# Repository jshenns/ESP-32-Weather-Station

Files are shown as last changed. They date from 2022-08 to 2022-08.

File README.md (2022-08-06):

# ESP-32-Weather-Station
Weather station that can send data to you via wifi. Meausres temperature, pressure, humidity. Also detects Lightning.

I wanted a weather station that could send data to me over wifi. This is it, it uses a BME-280 Sensor for temperature, pressure, and humidity. It uses an AS3935 Franklin lightning detector and 100nH coil for lightning detection. I initially prototyped it using the Sparkfun breakouts for those sensors, and then integrated everything into a PCB. Whole system centeres around the ESP-32 WROOM 32D module. The Blynk platform is used to stream the data over wifi for now.

Here is the board rendered in Eagle:

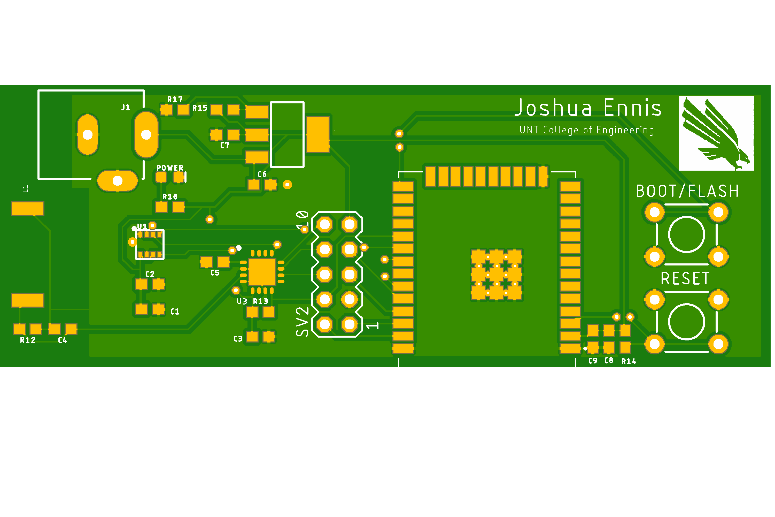
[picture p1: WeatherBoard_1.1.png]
board


Here is the board IRL:

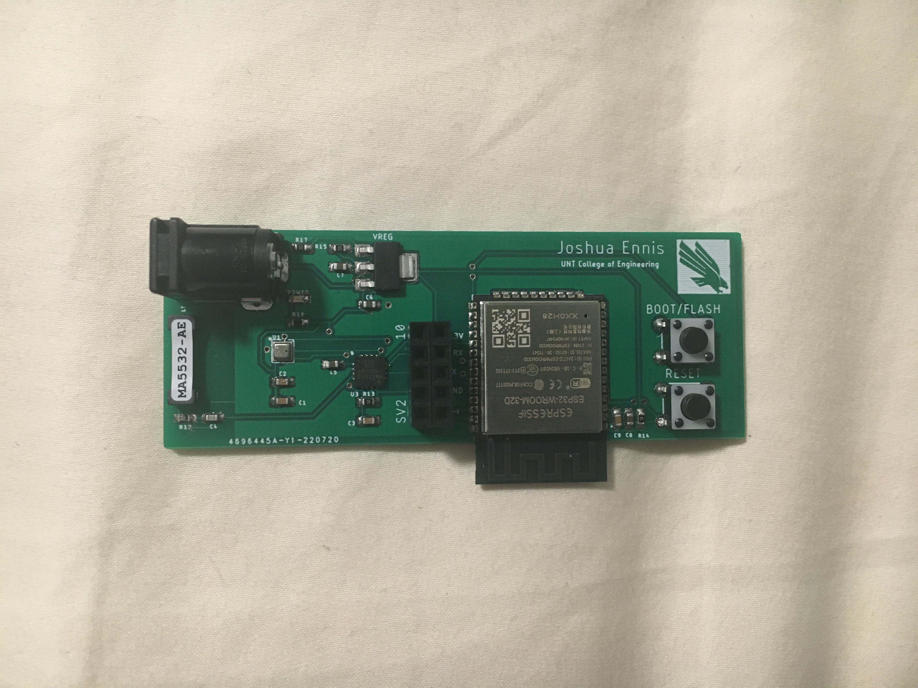
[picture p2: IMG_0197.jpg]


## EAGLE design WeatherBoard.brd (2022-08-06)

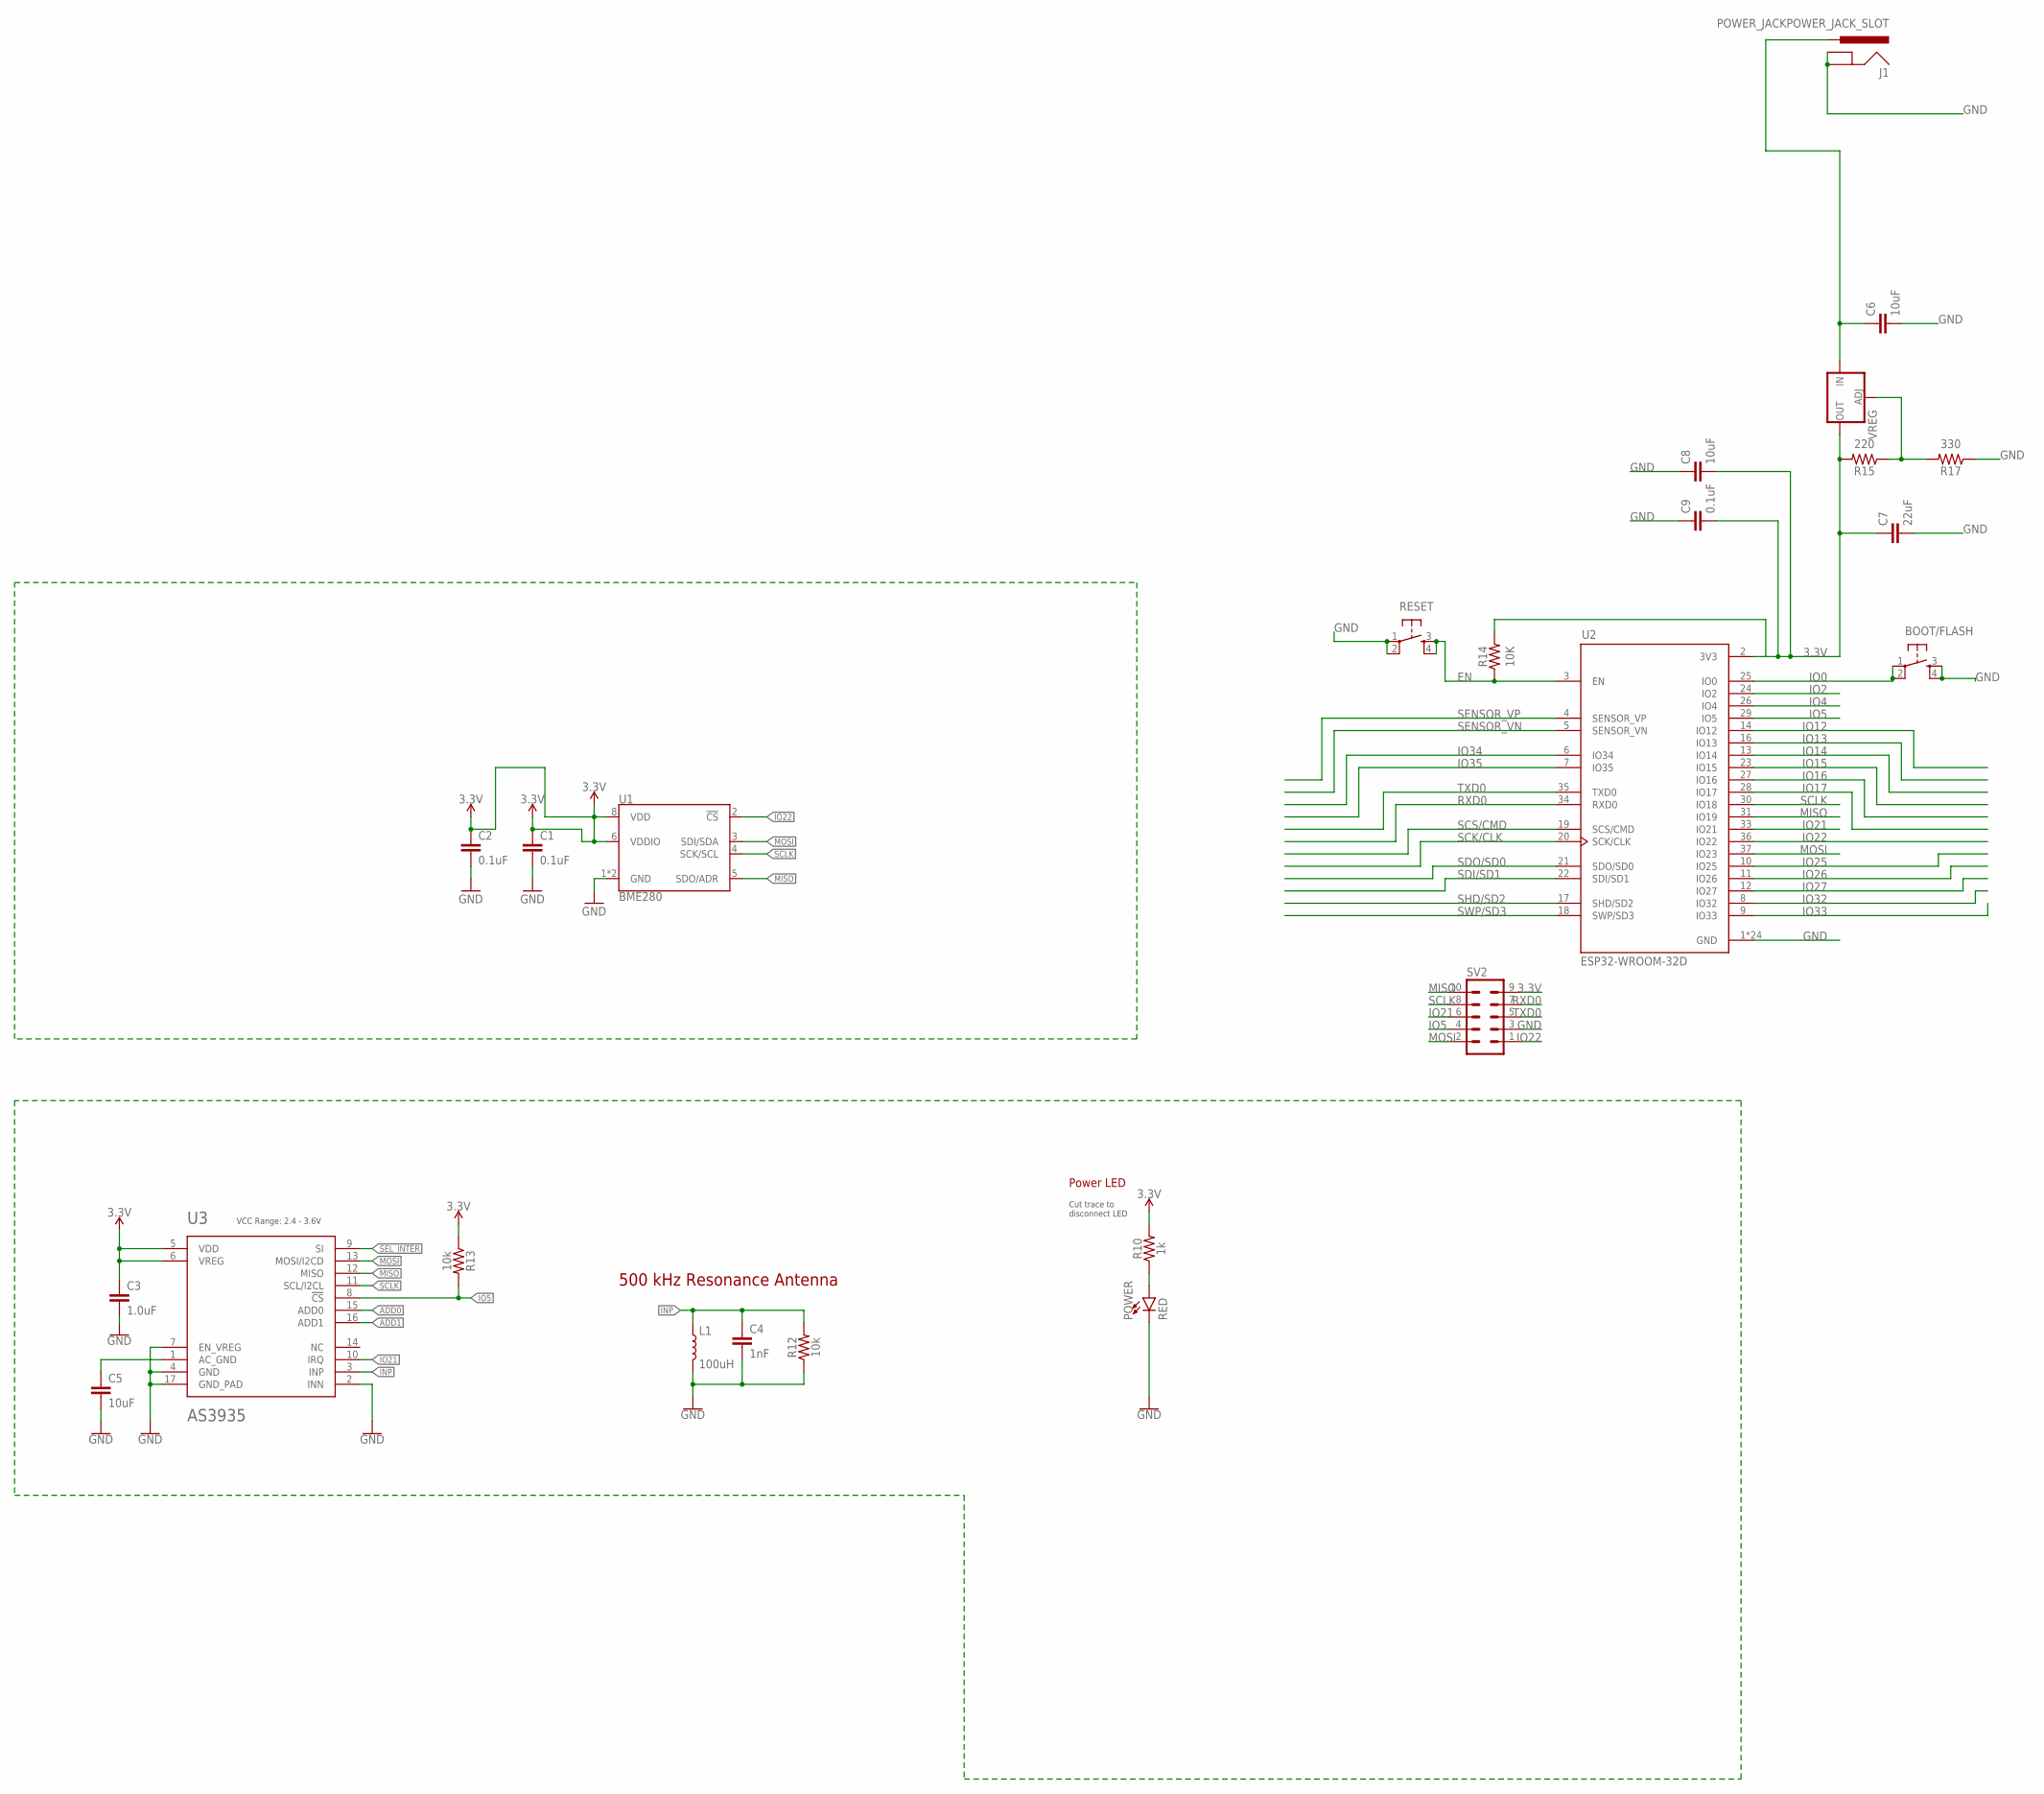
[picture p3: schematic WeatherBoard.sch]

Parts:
BOOT/FLASH: TAC_SWITCHPTH; TACTILE-PTH
C1, C2, C9: 0.1uF; 0603
C3: 1.0uF; 0603
C4: 1nF; 0603
C5, C6, C8: 10uF; 0603
C7: 22uF; 0603
J1: POWER_JACKPOWER_JACK_SLOT; POWER_JACK_PTH_SLOT
L1: 100uH; MA5532-AE
POWER: RED; LED-0603
R10: 1k; 0603
R12, R13: 10k; 0603
R14: 10K; 0603
R15: 220; 0603
R17: 330; 0603
RESET: TAC_SWITCHPTH; TACTILE-PTH
SV2: MA05-2
U1: BME280; LGA-8-2.5X2.5
U2: ESP32-WROOM-32D; MODULE_ESP32-WROOM-32D
U3: AS3935; 16LD_MLPQ
VREG: ADJWEATHERSTATION; VREG_NCP1117STAT3G

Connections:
3.3V: C1.1, C2.1, C3.1, C7.1, C8.2, C9.2, R10.2, R13.1, R14.2, R15.2, SV2.9, U1.6 (VDDIO), U1.8 (VDD), U2.2 (3V3), U3.5 (VDD), U3.6 (VREG), VREG.2 (OUT), VREG.4 (OUT)
ADD0: U3.15 (ADD0)
ADD1: U3.16 (ADD1)
EN: R14.1, RESET.3, RESET.4, U2.3 (EN)
GND: BOOT/FLASH.3, BOOT/FLASH.4, C1.2, C2.2, C3.2, C4.2, C5.2, C6.2, C7.2, C8.1, C9.1, J1.GND, J1.GNDBREAK, L1.2, POWER.C, R12.1, R17.1, RESET.1, RESET.2, SV2.3, U1.1 (GND), U1.7 (GND), U2.1 (GND), U2.15 (GND), U2.38 (GND), U2.39_1 (GND), U2.39_2 (GND), U2.39_3 (GND), U2.39_4 (GND), U2.39_5 (GND), U2.39_6 (GND), U2.39_7 (GND), U2.39_8 (GND), U2.39_9 (GND), U2.39_10 (GND), U2.39_11 (GND), U2.39_12 (GND), U2.39_13 (GND), U2.39_14 (GND), U2.39_15 (GND), U2.39_16 (GND), U2.39_17 (GND), U2.39_18 (GND), U2.39_19 (GND), U2.39_20 (GND), U2.39_21 (GND), U3.2 (INN), U3.4 (GND), U3.7 (EN_VREG), U3.17 (GND_PAD)
INP: C4.1, L1.1, R12.2, U3.3 (INP)
IO0: BOOT/FLASH.1, BOOT/FLASH.2, U2.25 (IO0)
IO2: U2.24 (IO2)
IO4: U2.26 (IO4)
IO5: R13.2, SV2.4, U2.29 (IO5), U3.8 (!CS)
IO12: U2.14 (IO12)
IO13: U2.16 (IO13)
IO14: U2.13 (IO14)
IO15: U2.23 (IO15)
IO16: U2.27 (IO16)
IO17: U2.28 (IO17)
IO21: SV2.6, U2.33 (IO21), U3.10 (IRQ)
IO22: SV2.1, U1.2 (!CS), U2.36 (IO22)
IO25: U2.10 (IO25)
IO26: U2.11 (IO26)
IO27: U2.12 (IO27)
IO32: U2.8 (IO32)
IO33: U2.9 (IO33)
IO34: U2.6 (IO34)
IO35: U2.7 (IO35)
MISO: SV2.10, U1.5 (SDO/ADR), U2.31 (IO19), U3.12 (MISO)
MOSI: SV2.2, U1.3 (SDI/SDA), U2.37 (IO23), U3.13 (MOSI/I2CD)
unnamed: C5.1, U3.1 (AC_GND)
unnamed: POWER.A, R10.1
unnamed: R15.1, R17.2, VREG.1 (ADJ)
unnamed: C6.1, J1.PWR, VREG.3 (IN)
RXD0: SV2.7, U2.34 (RXD0)
SCK/CLK: U2.20 (SCK/CLK)
SCLK: SV2.8, U1.4 (SCK/SCL), U2.30 (IO18), U3.11 (SCL/I2CL)
SCS/CMD: U2.19 (SCS/CMD)
SDI/SD1: U2.22 (SDI/SD1)
SDO/SD0: U2.21 (SDO/SD0)
SEL_INTER: U3.9 (SI)
SENSOR_VN: U2.5 (SENSOR_VN)
SENSOR_VP: U2.4 (SENSOR_VP)
SHD/SD2: U2.17 (SHD/SD2)
SWP/SD3: U2.18 (SWP/SD3)
TXD0: SV2.5, U2.35 (TXD0)

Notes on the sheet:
500 kHz Resonance Antenna
VCC Range: 2.4 - 3.6V
Cut trace to disconnect LED
Power LED

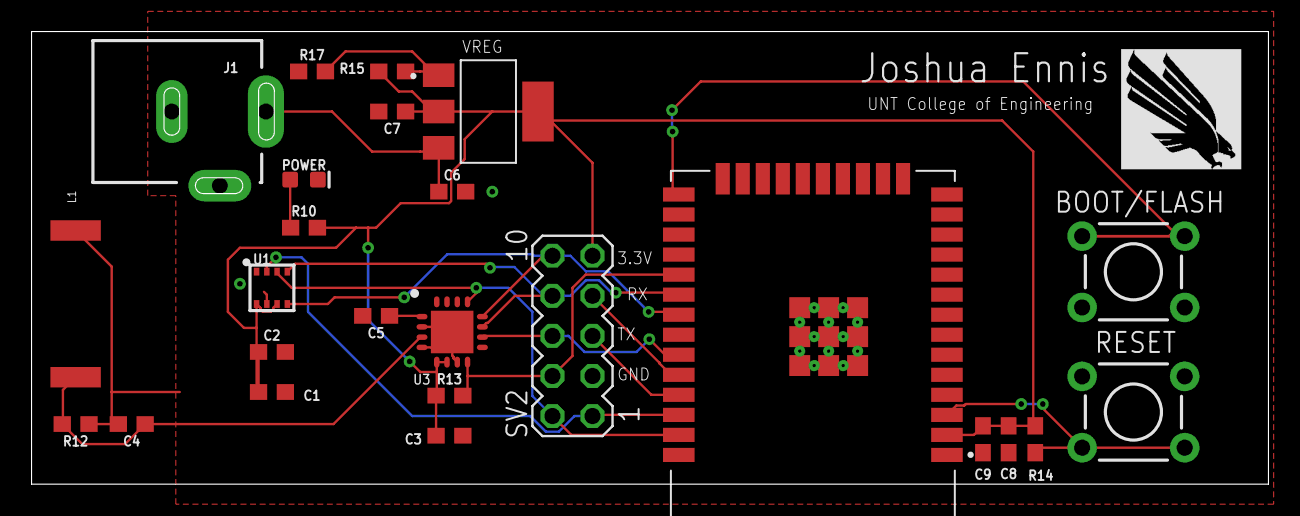
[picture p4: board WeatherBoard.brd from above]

Board: 2 copper layers, 78.4 x 28.7 mm, 25 parts (0 on the bottom side), 17 nets.

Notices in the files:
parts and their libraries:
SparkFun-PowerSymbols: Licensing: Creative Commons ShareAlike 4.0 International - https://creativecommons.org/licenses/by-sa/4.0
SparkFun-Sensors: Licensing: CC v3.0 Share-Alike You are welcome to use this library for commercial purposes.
